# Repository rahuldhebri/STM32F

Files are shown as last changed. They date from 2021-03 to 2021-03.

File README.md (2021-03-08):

# STM32F4
* STM32F4 microcontroller board with 10 GPIO pins with terminal connectors, SWD, I2C, USART & USB for DFU.
* Designed in KiCAD all source and manufacturing files included.
* Assembly and Gerber files are in format which JLCPCB uses and all parts used are basic parts so additional cost is not charged for using extended parts.
* Feel free to make any changes and use for your project and also mention suggestions/improvements/issues.

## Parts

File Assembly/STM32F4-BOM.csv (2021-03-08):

Comment | Designator | Footprint | LCSC
10nF | C1 | Capacitor_SMD:C_0603_1608Metric | C57112
100nF | C6,C7,C8,C9,C10 | Capacitor_SMD:C_0402_1005Metric | C1525
10nF | C12 | Capacitor_SMD:C_0402_1005Metric | C1523
2.2uF | C13,C14 | Capacitor_SMD:C_0603_1608Metric | C23630
12pF | C15,C16 | Capacitor_SMD:C_0402_1005Metric | C1547
33pF | C2 | Capacitor_SMD:C_0603_1608Metric | C1663
10uF | C3,C11 | Capacitor_SMD:C_0805_2012Metric | C15850
4.7uF | C4 | Capacitor_SMD:C_0805_2012Metric | C1779
4.7uF | C5 | Capacitor_SMD:C_0402_1005Metric | C23733
B5819W | D1,D4 | Diode_SMD:D_SOD-123 | C8598
RED | D2 | LED_SMD:LED_0603_1608Metric | C2286
ZMM 5V6 | D3 | Diode_SMD:D_MiniMELF | C8062
BLUE | D5 | LED_SMD:LED_0603_1608Metric | C72041
600@600MHz | FB1 | Inductor_SMD:L_0805_2012Metric | C1017
MountingHole_Pad | H1,H2,H3,H4 | MountingHole:MountingHole_3.2mm_M3_Pad_Via
Screw_Terminal_01x02 | J1 | TerminalBlock_Phoenix:TerminalBlock_Phoenix_MKDS-3-2-5.08_1x02_P5.08mm_Horizontal
Screw_Terminal_01x10 | J2 | TerminalBlock_Phoenix:TerminalBlock_Phoenix_MKDS-1,5-10_1x10_P5.00mm_Horizontal
SWD | J3 | Connector_PinHeader_1.27mm:PinHeader_2x05_P1.27mm_Vertical_SMD
Conn_01x04 | J4,J5 | Connector_Molex:Molex_SL_171971-0004_1x04_P2.54mm_Vertical
USB_B_Micro | J6 | Connector_USB:USB_Micro-B_Amphenol_10103594-0001LF_Horizontal
2.2uH | L1 | Inductor_SMD:L_1210_3225Metric | C1043
39nH | L2 | Inductor_SMD:L_0402_1005Metric | C25808
AO3401A | Q1 | Package_TO_SOT_SMD:SOT-23 | C15127
120K | R1 | Resistor_SMD:R_0603_1608Metric | C25808
10k | R10 | Resistor_SMD:R_0402_1005Metric | C25744
47 | R11 | Resistor_SMD:R_0603_1608Metric | C23182
2.2K | R12,R13 | Resistor_SMD:R_0603_1608Metric | C4190
100K | R2,R6 | Resistor_SMD:R_0603_1608Metric
75K | R3,R4 | Resistor_SMD:R_0603_1608Metric | C23242
1.5K | R5,R9 | Resistor_SMD:R_0603_1608Metric | C22843
68K | R7 | Resistor_SMD:R_0603_1608Metric | C23231
1K | R8 | Resistor_SMD:R_0603_1608Metric | C21190
SW_SPDT | SW1 | Button_Switch_THT:SW_CuK_OS102011MA1QN1_SPDT_Angled
MP2451 | U1 | Package_TO_SOT_SMD:SOT-23-6 | C14123
SRV05-4 | U2 | Package_TO_SOT_SMD:SOT-23-6 | C85364
STM32F405RGT6 | U3 | Package_QFP:LQFP-64_10x10mm_P0.5mm | C15742
16MHz | Y1 | Crystal:Crystal_SMD_3225-4Pin_3.2x2.5mm | C13738

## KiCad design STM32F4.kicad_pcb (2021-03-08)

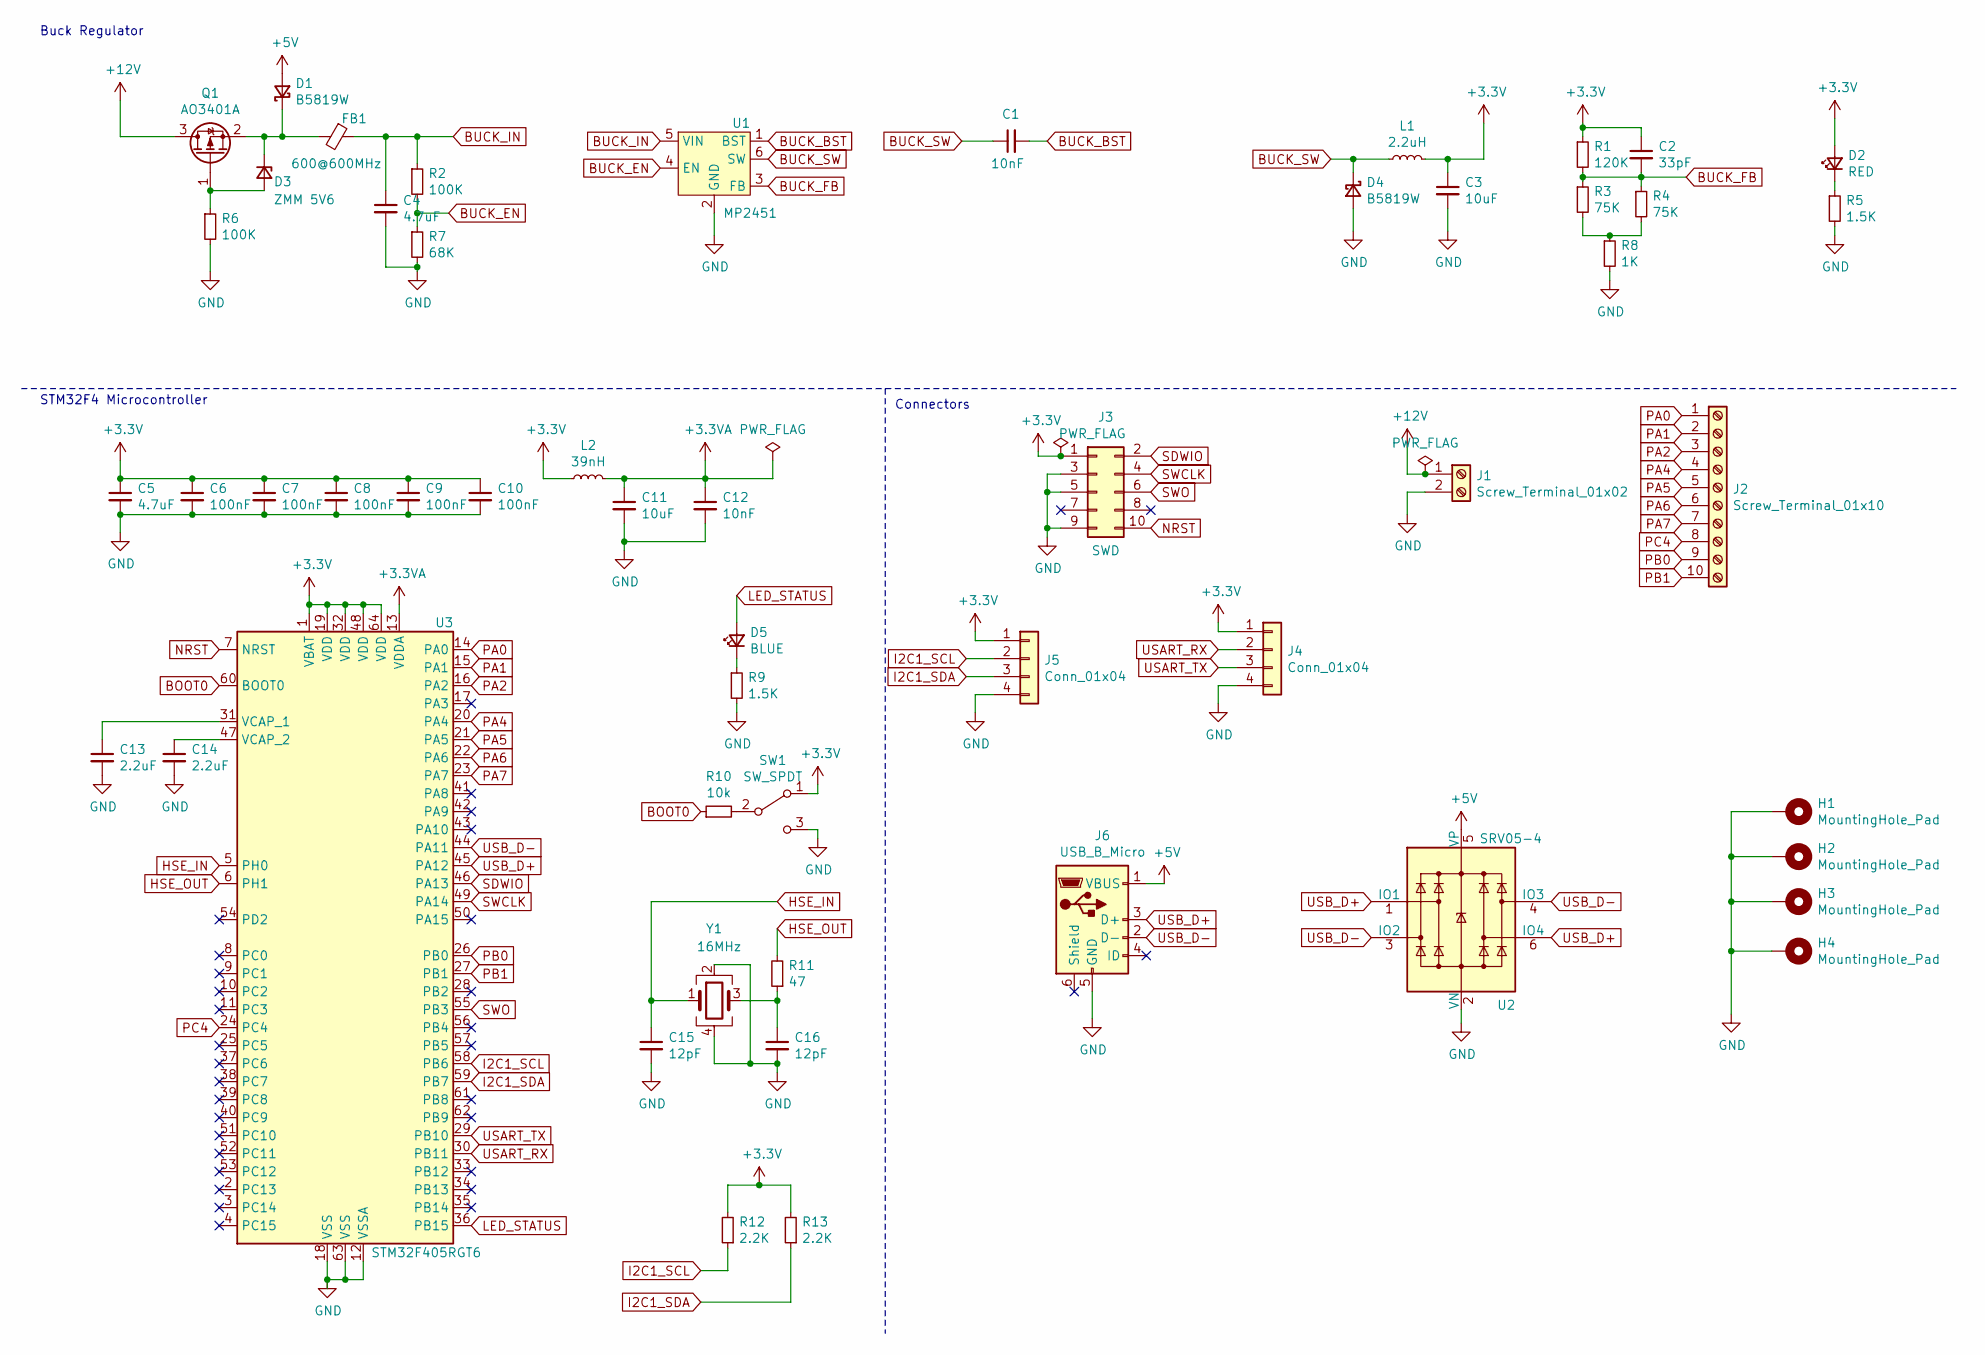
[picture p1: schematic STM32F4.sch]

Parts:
C1: 10nF; C_0603_1608Metric; LCSC C57112
C2: 33pF; C_0603_1608Metric; LCSC C1663
C3, C11: 10uF; C_0805_2012Metric; LCSC C15850
C4: 4.7uF; C_0805_2012Metric; LCSC C1779
C5: 4.7uF; C_0402_1005Metric; LCSC C23733
C6, C7, C8, C9, C10: 100nF; C_0402_1005Metric; LCSC C1525
C12: 10nF; C_0402_1005Metric; LCSC C1523
C13, C14: 2.2uF; C_0603_1608Metric; LCSC C23630
C15, C16: 12pF; C_0402_1005Metric; LCSC Part # C1547
D1, D4: B5819W; D_SOD-123; LCSC C8598
D2: RED; LED_0603_1608Metric; LCSC C2286
D3: ZMM 5V6; D_MiniMELF; LCSC Part # C8062
D5: BLUE; LED_0603_1608Metric; LCSC Part # C72041
FB1: 600@600MHz; L_0805_2012Metric; LCSC C1017
H1, H2, H3, H4: MountingHole_Pad; MountingHole_3.2mm_M3_Pad_Via
J1: Screw_Terminal_01x02; TerminalBlock_Phoenix_MKDS-3-2-5.08_1x02_P5.08mm_Horizontal
J2: Screw_Terminal_01x10; TerminalBlock_Phoenix_MKDS-1,5-10_1x10_P5.00mm_Horizontal
J3: SWD; PinHeader_2x05_P1.27mm_Vertical_SMD
J4, J5: Conn_01x04; Molex_SL_171971-0004_1x04_P2.54mm_Vertical
J6: USB_B_Micro; USB_Micro-B_Amphenol_10103594-0001LF_Horizontal
L1: 2.2uH; L_1210_3225Metric; LCSC Part # C1043
L2: 39nH; L_0402_1005Metric; LCSC Part # C25808
Q1: AO3401A; SOT-23; LCSC Part # C15127
R1: 120K; R_0603_1608Metric; LCSC Part # C25808
R2: 100K; R_0603_1608Metric; LCSC Part # C25803
R3, R4: 75K; R_0603_1608Metric; LCSC Part # C23242
R5, R9: 1.5K; R_0603_1608Metric; LCSC C22843
R6: 100K; R_0603_1608Metric; LCSC C25803
R7: 68K; R_0603_1608Metric; LCSC Part # C23231
R8: 1K; R_0603_1608Metric; LCSC Part # C21190
R10: 10k; R_0402_1005Metric; LCSC Part # C25744
R11: 47; R_0603_1608Metric; LCSC Part # C23182
R12, R13: 2.2K; R_0603_1608Metric; LCSC Part # C4190
SW1: SW_SPDT; SW_CuK_OS102011MA1QN1_SPDT_Angled
U1: MP2451; SOT-23-6; LCSC Part # C14123
U2: SRV05-4; SOT-23-6; LCSC Part # C85364
U3: STM32F405RGT6; LQFP-64_10x10mm_P0.5mm; LCSC Part # C15742
Y1: 16MHz; Crystal_SMD_3225-4Pin_3.2x2.5mm; LCSC Part # C13738

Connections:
+3.3VA: C11.1, C12.1, L2.2, U3.13 (VDDA)
+3V3: C2.1, C3.1, C5.1, C6.1, C7.1, C8.1, C9.1, C10.1, D2.2 (A), J3.1, J4.1, J5.1, L1.2, L2.1, R1.1, R12.2, R13.2, SW1.1 (A), U3.1 (VBAT), U3.19 (VDD), U3.32 (VDD), U3.48 (VDD), U3.64 (VDD)
+5V: D1.2 (A), J6.1 (VBUS), U2.5 (VP)
+12V: J1.1, Q1.3 (D)
BOOT0: R10.1, U3.60 (BOOT0)
BUCK_BST: C1.2, U1.1 (BST)
BUCK_EN: R2.2, R7.1, U1.4 (EN)
BUCK_FB: C2.2, R1.2, R3.1, R4.1, U1.3 (FB)
BUCK_IN: C4.1, FB1.1, R2.1, U1.5 (VIN)
BUCK_SW: C1.1, D4.1 (K), L1.1, U1.6 (SW)
GND: C3.2, C4.2, C5.2, C6.2, C7.2, C8.2, C9.2, C10.2, C11.2, C12.2, C13.2, C14.2, C15.2, C16.2, D4.2 (A), H1.1, H2.1, H3.1, H4.1, J1.2, J3.3, J3.5, J3.9, J4.4, J5.4, J6.5 (GND), R5.2, R6.2, R7.2, R8.2, R9.2, SW1.3 (C), U1.2 (GND), U2.2 (VN), U3.12 (VSSA), U3.18 (VSS), U3.63 (VSS), Y1.2, Y1.4
HSE_IN: C15.1, U3.5 (PH0), Y1.1
HSE_OUT: R11.2, U3.6 (PH1)
I2C1_SCL: J5.2, R12.1, U3.58 (PB6)
I2C1_SDA: J5.3, R13.1, U3.59 (PB7)
LED_STATUS: D5.2 (A), U3.36 (PB15)
NRST: J3.10, U3.7 (NRST)
unnamed: C13.1, U3.31 (VCAP_1)
unnamed: C14.1, U3.47 (VCAP_2)
unnamed: C16.1, R11.1, Y1.3
unnamed: D1.1 (K), D3.1 (K), FB1.2, Q1.2 (S)
unnamed: D2.1 (K), R5.1
unnamed: D3.2 (A), Q1.1 (G), R6.1
unnamed: D5.1 (K), R9.1
unnamed: R3.2, R4.2, R8.1
unnamed: R10.2, SW1.2 (B)
PA0: J2.1, U3.14 (PA0)
PA1: J2.2, U3.15 (PA1)
PA2: J2.3, U3.16 (PA2)
PA4: J2.4, U3.20 (PA4)
PA5: J2.5, U3.21 (PA5)
PA6: J2.6, U3.22 (PA6)
PA7: J2.7, U3.23 (PA7)
PB0: J2.9, U3.26 (PB0)
PB1: J2.10, U3.27 (PB1)
PC4: J2.8, U3.24 (PC4)
SDWIO: J3.2, U3.46 (PA13)
SWCLK: J3.4, U3.49 (PA14)
SWO: J3.6, U3.55 (PB3)
USART_RX: J4.2, U3.30 (PB11)
USART_TX: J4.3, U3.29 (PB10)
USB_D+: J6.3 (D+), U2.1 (IO1), U2.6 (IO4), U3.45 (PA12)
USB_D-: J6.2 (D-), U2.3 (IO2), U2.4 (IO3), U3.44 (PA11)

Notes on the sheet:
STM32F4 Microcontroller
Buck Regulator
Connectors

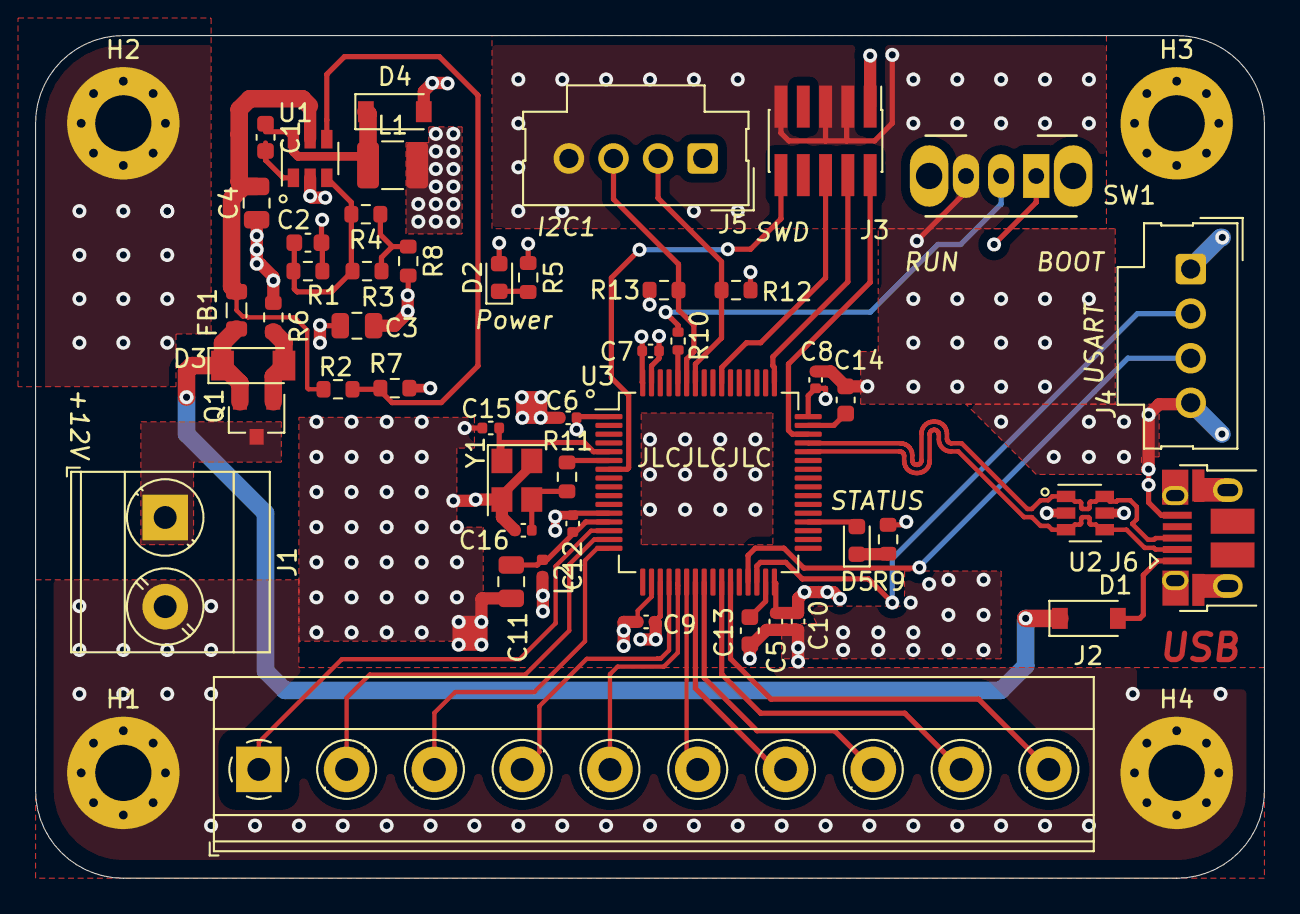
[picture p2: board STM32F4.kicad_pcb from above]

Board: 4 copper layers, 70.0 x 48.0 mm, 53 parts (0 on the bottom side), 43 nets.
